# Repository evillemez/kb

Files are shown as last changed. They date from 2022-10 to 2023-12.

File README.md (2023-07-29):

This projects contains the definition and build environment for generating a custom keyboard using Ergogen.

* `keyboards/` - each directory here is a separate keyboard meant to be used as input for ergogen. There may be git submodules in some keyboard directories for side-loading ergogen footprints from other places.
* `archive/` - previous attempts at experimenting with possible layouts. Kept for personal reference.  Some use older versions of the ergogen config, are none are expected to be complete or actually work.

## Initial setup

Getting setup initially, you need to do the following:

* initialize submodules recursively, and/or run `make init`
* build the docker container for the general build environment: `make build`
* run the container: `make shell`
* install the ergogen via `yarn` from within the container: `yarn install`

After that, you should be able to run ergogen within the container to build any of the keyboads defined in  `keyboards/`.

## Developing

Use ergogen.cache.works to more easily edit the `config.yml` file in `keyboard/` and see changes.  Just copy/paste them back to commit changes.

To run ergogen locally, connect to the container and run the ergogen command to generate the files:

* `make shell` to connect to container
* Run erogen on any keyboard defined in a subdirectory, or use the makefile shortcut from the root directory: `make gen KB=elv`

Inspect the makefile if you want the see the exact commands and arguments.

## Resources & Prior Art

Major thanks for, and inspiration from the following resources:

* Ergogen:
  * https://ergogen.xyz
  * https://ergogen.cache.works
* Build guide by FlatFootFox: https://flatfootfox.com/ergogen-introduction
* Experiments in automatic build systems & autorouting:
  * https://github.com/soundmonster/samoklava
  * https://github.com/tbaumann/typematrix_split_ergogen
  * https://github.com/ceoloide/corney-island

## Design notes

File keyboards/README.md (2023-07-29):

One gotcha to be aware of:  The name of the subdirectory for a specific keyboard must match the name of the keyboard defined in `pcbs.*` in the respective `config.yml`.

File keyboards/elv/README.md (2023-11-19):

My main keyboard: a monoblock split.  Wiring should be roughly the same as a Planck, just slightly different physical layout.

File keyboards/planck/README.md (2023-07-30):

This keyboard was originally copied from the examples at https://ergogen.cache.works/.

I may modify this slightly and build it, since I actually use a Planck.  Having a low-profile wireless version is desirable.

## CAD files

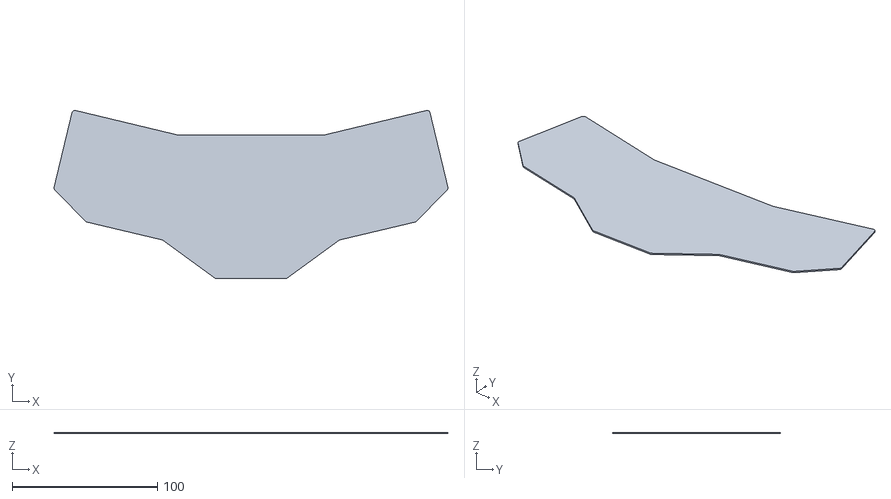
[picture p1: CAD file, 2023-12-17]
keyboards/elv/output/cases/bottom.stl
271.7 x 116.0 x 1.00

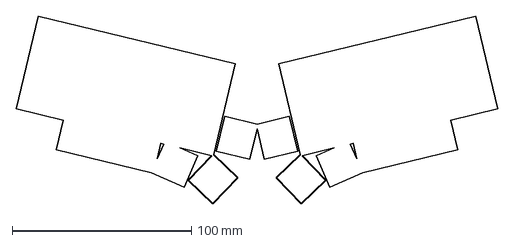
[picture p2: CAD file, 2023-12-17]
keyboards/elv/output/outlines/raw.dxf
268.5 x 104.5 mm

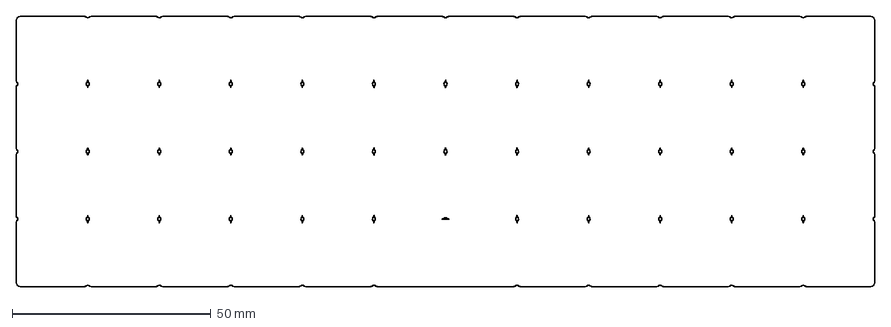
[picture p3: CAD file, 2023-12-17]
keyboards/planck/output/outlines/panel.dxf
216.0 x 68.0 mm

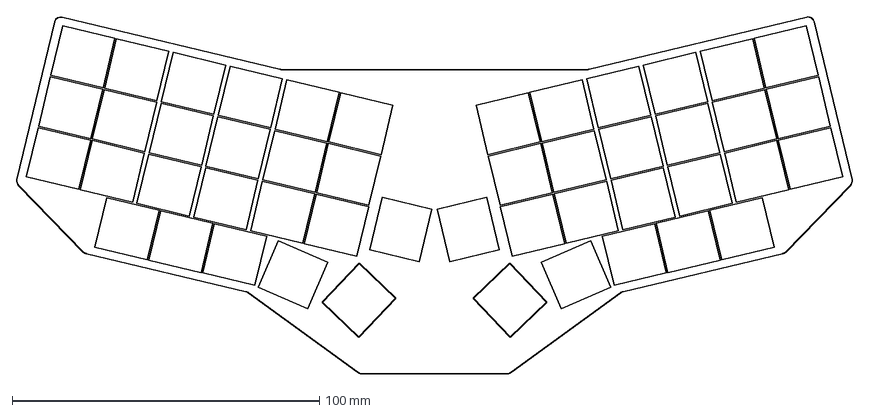
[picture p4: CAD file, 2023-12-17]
keyboards/elv/output/outlines/combo.dxf
271.9 x 116.2 mm

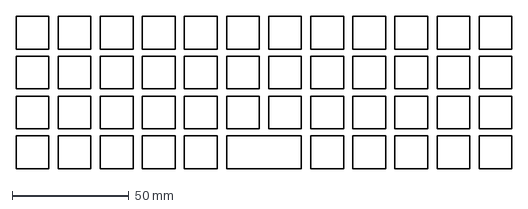
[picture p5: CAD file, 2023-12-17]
keyboards/planck/output/outlines/switch_cutouts.dxf
212.0 x 65.0 mm

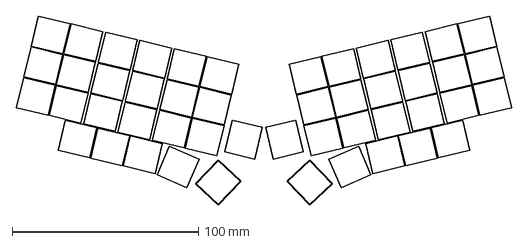
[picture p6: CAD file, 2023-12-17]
keyboards/elv/output/outlines/keys.dxf
265.5 x 101.3 mm

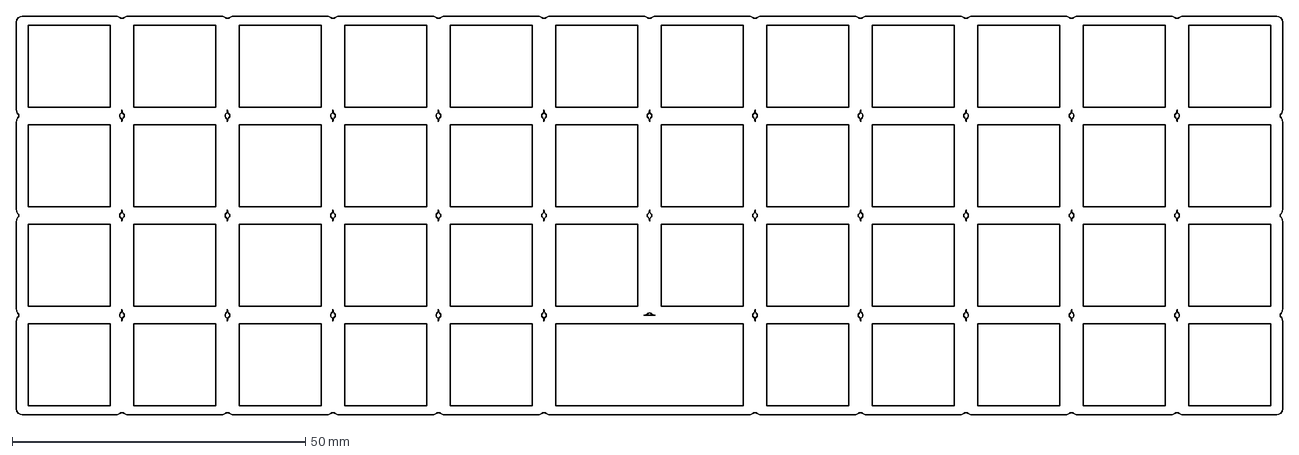
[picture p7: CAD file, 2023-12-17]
keyboards/planck/output/outlines/switch_plate.dxf
216.0 x 68.0 mm

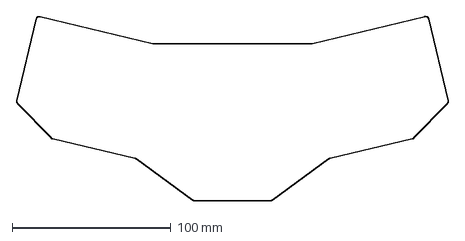
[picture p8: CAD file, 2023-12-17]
keyboards/elv/output/outlines/board.dxf
271.9 x 116.2 mm

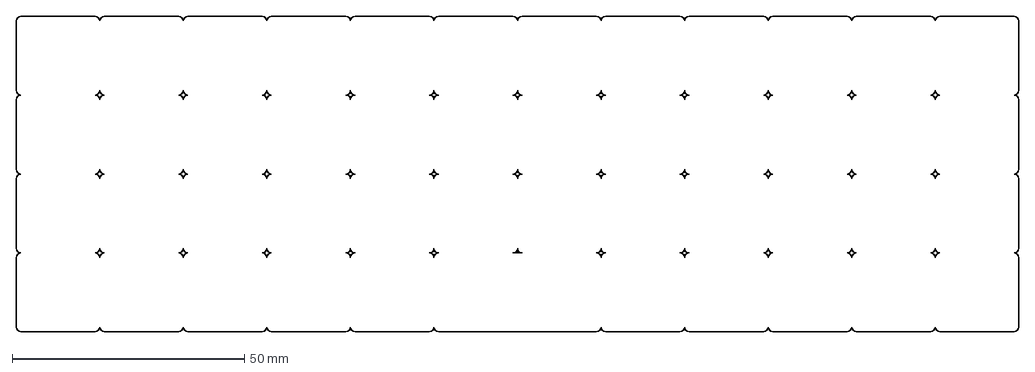
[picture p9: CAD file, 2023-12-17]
keyboards/planck/output/outlines/raw.dxf
216.0 x 68.0 mm

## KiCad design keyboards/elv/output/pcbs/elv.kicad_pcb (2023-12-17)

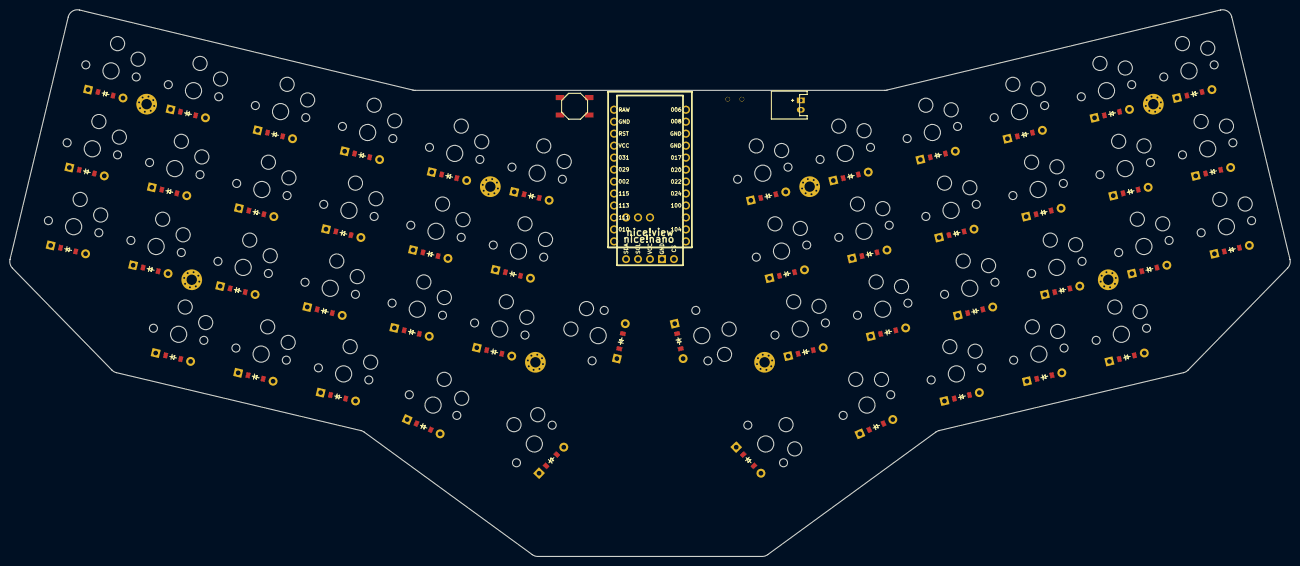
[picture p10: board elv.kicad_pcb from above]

Board: 2 copper layers, 271.7 x 116.0 mm, 109 parts (0 on the bottom side), 70 nets, no tracks yet.

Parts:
B1: SW_TACT_ALPS_SKQGABE010
D1, D2, D3, D4, D5, D6, D7, D8, D9, D10, D11, D12, D13, D14, D15, D16, D17, D18, D19, D20, D21, D22, D23, D24, D25, D26, D27, D28, D29, D30, D31, D32, D33, D34, D35, D36, D37, D38, D39, D40, D41, D42, D43, D44, D45, D46, D47, D48: ComboDiode
JST1: JST_PH_S2B-PH-K_02x2.00mm_Angled
MCU1: nice_nano
S1, S2, S3, S4, S5, S6, S7, S8, S9, S10, S11, S12, S13, S14, S15, S16, S17, S18, S19, S20, S21, S22, S23, S24, S25, S26, S27, S28, S29, S30, S31, S32, S33, S34, S35, S36, S37, S38, S39, S40, S41, S42, S43, S44, S45, S46, S47, S48: PG1350
T1: SPDT_C128955
_1, _2, _3, _4, _5, _6, _7, _8: MountingHole_2.2mm_M2_Pad_Via
niceView1: niceView; niceView_headers

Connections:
BAT: JST1.1, T1.2
GND: B1.1, JST1.2, MCU1.3, MCU1.4, MCU1.23, niceView1.2
P002: MCU1.18, S7.1, S8.1, S9.1, S21.1, S31.1, S32.1, S33.1, S45.1
P006: MCU1.1, niceView1.5
P008: MCU1.2, niceView1.4
P009: D19.1, D20.1, D21.1, D22.1, D23.1, D24.1, MCU1.13
P010: D1.1, D4.1, D7.1, D10.1, D13.1, D16.1, MCU1.14
P011: D25.1, D28.1, D31.1, D34.1, D37.1, D40.1, MCU1.10
P017: MCU1.5, niceView1.1
P020: MCU1.6, S13.1, S14.1, S15.1, S23.1, S37.1, S38.1, S39.1, S47.1
P022: MCU1.7, S16.1, S17.1, S18.1, S24.1, S40.1, S41.1, S42.1, S48.1
P024: D27.1, D30.1, D33.1, D36.1, D39.1, D42.1, MCU1.8
P029: MCU1.19, S4.1, S5.1, S6.1, S20.1, S28.1, S29.1, S30.1, S44.1
P031: MCU1.20, S1.1, S2.1, S3.1, S19.1, S25.1, S26.1, S27.1, S43.1
P100: D26.1, D29.1, D32.1, D35.1, D38.1, D41.1, MCU1.9
P104: D43.1, D44.1, D45.1, D46.1, D47.1, D48.1, MCU1.11
P111: D2.1, D5.1, D8.1, D11.1, D14.1, D17.1, MCU1.15
P113: D3.1, D6.1, D9.1, D12.1, D15.1, D18.1, MCU1.16
P115: MCU1.17, S10.1, S11.1, S12.1, S22.1, S34.1, S35.1, S36.1, S46.1
RAW: MCU1.24, T1.1
RST: B1.2, MCU1.22
VCC: MCU1.21, niceView1.3
aux_main: D24.2, S24.2
index_bottom: D13.2, S13.2
index_home: D14.2, S14.2
index_top: D15.2, S15.2
inner_bottom: D16.2, S16.2
inner_home: D17.2, S17.2
inner_top: D18.2, S18.2
middle_bottom: D10.2, S10.2
middle_home: D11.2, S11.2
middle_top: D12.2, S12.2
mirror_aux_main: D48.2, S48.2
mirror_index_bottom: D37.2, S37.2
mirror_index_home: D38.2, S38.2
mirror_index_top: D39.2, S39.2
mirror_inner_bottom: D40.2, S40.2
mirror_inner_home: D41.2, S41.2
mirror_inner_top: D42.2, S42.2
mirror_middle_bottom: D34.2, S34.2
mirror_middle_home: D35.2, S35.2
mirror_middle_top: D36.2, S36.2
mirror_mod1_main: D46.2, S46.2
mirror_mod2_main: D45.2, S45.2
mirror_mod3_main: D44.2, S44.2
mirror_mod4_main: D43.2, S43.2
mirror_outer_bottom: D25.2, S25.2
mirror_outer_home: D26.2, S26.2
mirror_outer_top: D27.2, S27.2
mirror_pinky_bottom: D28.2, S28.2
mirror_pinky_home: D29.2, S29.2
mirror_pinky_top: D30.2, S30.2
mirror_primary_main: D47.2, S47.2
mirror_ring_bottom: D31.2, S31.2
mirror_ring_home: D32.2, S32.2
mirror_ring_top: D33.2, S33.2
mod1_main: D22.2, S22.2
mod2_main: D21.2, S21.2
mod3_main: D20.2, S20.2
mod4_main: D19.2, S19.2
outer_bottom: D1.2, S1.2
outer_home: D2.2, S2.2
outer_top: D3.2, S3.2
pinky_bottom: D4.2, S4.2
pinky_home: D5.2, S5.2
pinky_top: D6.2, S6.2
primary_main: D23.2, S23.2
ring_bottom: D7.2, S7.2
ring_home: D8.2, S8.2
ring_top: D9.2, S9.2

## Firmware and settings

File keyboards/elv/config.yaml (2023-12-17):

# defining some unit proxy references, mostly for making it
# easier to make global changes later
units:
  # for spacing of keycaps
  kx: cx
  ky: cy
  # for padding between keycaps
  px: kx + 2
  py: ky + 2
  # extra for edge of the board
  dx: kx + 5
  dy: ky + 5
points:
  rotate: -13.5
  mirror: &mirror
    ref: thumb_aux_main
    distance: 22
  zones:
    main:
      anchor:
        # for positioning in KiCad
        shift: [100, -100]
      key:
        padding: 1ky
        spread: 1kx
      columns:
        outer:
          key.column_net: P031
        pinky:
          key.column_net: P029
        ring:
          key:
            spread: u
            column_net: P002
        middle:
          key:
            spread: u
            column_net: P115
        index:
          key:
            spread: u
            column_net: P020
        inner:
          key.column_net: P022
      rows:
        bottom:
          row_net: P010
          mirror.row_net: P011
        home:
          row_net: P111
          mirror.row_net: P100
        top:
          row_net: P113
          mirror.row_net: P024
    thumb:
      key: 
        padding: 1ky
        spread: 1kx        
      anchor:
        ref: main_outer_bottom
        shift: [1.5kx, -ky]
      rows:
        main:
          row_net: P009
          mirror.row_net: P104
      columns:
        mod4:
          key.column_net: P031
        mod3:
          key.column_net: P029
        mod2:
          key.column_net: P002
        mod1:
          key:
            splay: -10
            spread: kx+2
            stagger: -2
            column_net: P115
        primary:
          key:
            splay: 70
            spread: kx+5
            stagger: 1
            width: 1.5kx
            column_net: P020
        aux:
          key:
            splay: 30
            spread: kx+8
            stagger: 6
            column_net: P022
outlines:
  raw:
    - what: rectangle
      where: true
      size: [px, py]
  keys:
    - what: rectangle
      where: true
      size: [kx-0.5, ky-0.5]
  board:
    - what: polygon
      operation: stack
      fillet: 2
      # starting at top-left of board, going counter clockwise
      # and shifting points to edge of key
      points:
        - ref: main_outer_top
          shift: [-0.5dx, 0.5dy]
        - ref: main_outer_bottom
          shift: [-0.5dx, -0.5dy]
        - ref: thumb_mod4_main
          shift: [-0.5dx, -0.5dy]
        - ref: thumb_mod1_main
          shift: [-0.5dx, -0.5dy]
        - ref: thumb_primary_main
          shift: [-0.75dx, -0.75dy]
        - ref: mirror_thumb_primary_main
          shift: [-0.75dx, -0.75dy]
        - ref: mirror_thumb_mod1_main
          shift: [-0.5dx, -0.5dy]
        - ref: mirror_thumb_mod4_main
          shift: [-0.5dx, -0.5dy]
        - ref: mirror_main_outer_bottom
          shift: [-0.5dx, -0.5dy]
        - ref: mirror_main_outer_top
          shift: [-0.5dx, 0.5dy]
        - ref: mirror_main_index_top
          shift: [-0.5dx, 0.5dy]
        - ref: main_index_top
          shift: [-0.5dx, 0.5dy]
  combo:
    - name: board
    - operation: subtract
      name: keys
      
pcbs:
  elv:
    outlines:
      main:
        outline: board
    footprints:
      choc_hotswap:
        what: choc
        where: true
        params:
          keycaps: true
          reverse: false
          hotswap: true
          from: "{{column_net}}"
          to: "{{colrow}}"
      diode:
        what: diode
        where: true
        adjust:
          shift: [0, -5]
        params:
          from: "{{colrow}}"
          to: "{{row_net}}"
      nicenano:
        what: nice_nano
        params:
          orientation: "down"
        where:
          ref.aggregate.parts: [main_inner_top, mirror_main_inner_top]
          shift: [0, -0.5]
          rotate: -90      
      niceview:
        what: nice_view
        params:
          SDA: P006
          SCL: P008
          CS: P017
        where:
          ref.aggregate.parts: [main_inner_home, mirror_main_inner_home]
          shift: [0, -3]
          rotate: 90
      reset:
        what: button
        params:
          from: GND
          to: RST
        where:
          ref.aggregate.parts: [main_index_top, mirror_main_index_top]
          shift: [-16, 10]
      battery:
        what: jstph
        params:
          pos: BAT
          neg: GND
          side: F
        where:
          ref.aggregate.parts: [main_index_top, mirror_main_index_top]
          shift: [32, 10.25]
          rotate: -90
      powerswitch:
        what: slider
        where:
          ref.aggregate.parts: [main_index_top, mirror_main_index_top]
          shift: [18, 11.5]
        params:
          from: RAW
          to: BAT
          side: B
      holeLeftOuterTop:
        what: mountinghole
        where:
          ref: [main_outer_top]
          shift: [0.5kx, -0.3ky]
      holeLeftPinkyBottom:
        what: mountinghole
        where:
          ref: [main_pinky_bottom]
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

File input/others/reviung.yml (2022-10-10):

units:
  # `U` is a predefined unit of measure that means 19.05mm, which is MX spacing
  angle: -8
points:
  zones:
    matrix:
      rotate: angle
      mirror: &mirror
        ref: matrix_inner_bottom
        shift: [0, -U]
        distance: 2.25U
      columns:
        outer:
          key:
            column_net: P4
            mirror.column_net: P9
        pinky:
          stagger: 0.25U
          key:
            column_net: P5
            mirror.column_net: P8
        ring:
          stagger: 0.25U
          key:
            column_net: P6
            mirror.column_net: P7
        middle:
          stagger: 0.25U
          key:
            column_net: P7
            mirror.column_net: P6
        index:
          stagger: -0.25U
          key:
            column_net: P8
            mirror.column_net: P5
        inner:
          stagger: -0.25U
          key:
            column_net: P9
            mirror.column_net: P4
      rows:
        bottom:
          padding: U
          row_net: P21
          mirror.row_net: P18
        home:
          padding: U
          row_net: P20
          mirror.row_net: P15
        top:
          padding: U
          row_net: P19
          mirror.row_net: P14
    thumb_middle:
      anchor:
        ref: [matrix_inner_bottom, mirror_matrix_inner_bottom]
        shift: [0, -1.15U]
      key:
        name: thumb_middle
        width: 2.25
        row_net: P16
        column_net: P6
    thumb_reachy:
      mirror: *mirror
      anchor:
        ref: thumb_middle
        shift: [-3.5U / 2 - 2 , 0.12U]
        rotate: angle
      key:
        name: thumb_reachy
        width: 1.25
        row_net: P16
        column_net: P20
        mirror.column_net: P15 
    thumb_tucky:
      mirror: *mirror
      anchor:
        ref: thumb_reachy
        shift: [-1.25U - 2, 0.4U]
        rotate: -angle
      key:
        name: thumb_tucky
        width: 1.25
        row_net: P16
        column_net: P21
        mirror.column_net: P14
  key:
    footprints:
      - type: mx
        nets:
          from: =row_net
          to: =column_net
        params.keycaps: true
      - type: diode
        anchor:
          shift: [0, -4.7]
        nets:
          from: =row_net
          to: =colrow
pcbs:
  simple_reviung41:
    footprints:
      - type: promicro
        anchor:
          - ref: [matrix_inner_top, mirror_matrix_inner_top]
            shift: [0, 22]
            rotate: angle

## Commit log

2022-10-01 added footprints section
2022-10-02 generating pcb without error, but all column nets need adjusting
2022-10-23 added colnets and rownets, and diodes, probably wrong and needs adjustment, unsure
2022-11-25 set nets for switches and diodes, added footprint for reset switch
2023-06-19 wip, working on footprints, diodes, nets, etc
2023-06-23 added footprints, need to figure out oled, battery, and reset switch
2023-07-23 added powerswitch and batter footprints
2023-07-23 added infused-kim footprints submodule
2023-07-23 re-added footprint submodule and reorganized repo
2023-07-24 tweaked positions of battery and powerswitch footprints
2023-07-27 added key matrix nets, still need correct wirings for niceview
    [config.yaml]
2023-07-29 did a thing for niceview based on what Ive found in someone elses repo, not sure that its correct
    [config.yaml]
2023-07-29 moved keyboard and footprint submodule to new structure
2023-07-29 autoroute build script mostly worked on the planck, errors generating images though
    [config.yaml]
2023-10-21 changed board rotation angle, and made minor resulting position changes to some components
2023-10-21 minor tweak to board rotation
2023-11-19 added nicenano and niceview footprints from another repo
2023-11-19 reworked col and row nets for new nicenano footprint
    [config.yaml]
2023-11-19 added mounting holes in prep for work on case
2023-11-19 installed jscad cli for case generation
2023-12-12 reworked nets for easier routing, at least that was the hope
    [config.yaml]
2023-12-17 switched jst and reset footprint locations
    [config.yaml]
2023-12-17 added routed pcbs in routed subdirectory
    [elv.kicad_pcb]
2023-12-17 added ergogen output files
    [board.dxf, bottom.stl, combo.dxf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]
2023-12-17 updated gitignore to exclude kicad cache file
